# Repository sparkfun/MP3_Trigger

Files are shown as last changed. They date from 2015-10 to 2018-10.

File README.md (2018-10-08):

MP3 Trigger
============

MP3 Trigger (https://cdn.sparkfun.com/assets/parts/1/1/2/2/7/13720-01.jpg)

[*MP3 Trigger (WIG-13720)*](https://www.sparkfun.com/products/13720)

 The MP3 Trigger board is built to make it MP3 sound integration easier than ever. 
 The board has 18 external trigger pins that will directly trigger pre-selected MP3 tracks, and a full-duplex serial control port that provides full transport control, remote triggering for up to 256 tracks, and fast real-time volume control. 
 
Repository Contents
-------------------
* **/Hardware** - All Eagle design files (.brd, .sch)
* **/Production** - Production files

Documentation
--------------
* **[Hookup Guide](https://learn.sparkfun.com/tutorials/mp3-trigger-hookup-guide-v24)** - Basic hookup guide for the MP3 Trigger.
* **[SparkFun Fritzing repo](https://github.com/sparkfun/Fritzing_Parts)** - Fritzing diagrams for SparkFun products.
* **[SparkFun 3D Model repo](https://github.com/sparkfun/3D_Models)** - 3D models of SparkFun products. 
* **[SparkFun Graphical Datasheets](https://github.com/sparkfun/Graphical_Datasheets)** -Graphical Datasheets for various SparkFun products.

License Information
-------------------

This product is _**open source**_! 

Please review the LICENSE.md file for license information. 

If you have any questions or concerns on licensing, please contact techsupport@sparkfun.com.

Distributed as-is; no warranty is given.

- Your friends at SparkFun.

_**Note:** This product is a collaboration with Robertsonics. A portion of each sales goes back to them for product support and continued development._

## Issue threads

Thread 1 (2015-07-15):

v24 Proto Checklist Issues

ericorosel, 2015-07-15:
(1) Sheet 2 needs a frame

(2) 7 4-way jumpers in sheet 2

(3) Dashed lines in SCH are on "Symbols" instead of "Info"

(4) LM1117 had wrong prefix

(5) Board "Dimension" outline is 10mil instead of 8mil

(6) I updated my Eagle_rules repo and loaded it into the design, it seemed to fix the via sizing issue. I'm think the DRU in the project is just outdated

(7) When the vias changed it threw a Clearance error/issue

(8) Need measures in BRD

(9) 1.8V vreg needs silk for footprint

that's it!

JoelEB, 2015-07-29:
(1) Sheet 2 needs a frame - Fixed

(2) 7 4-way jumpers in sheet 2 - Fixed

(3) Dashed lines in SCH are on "Symbols" instead of "Info" - Fixed

(4) LM1117 had wrong prefix - Changed to U4

(5) Board "Dimension" outline is 10mil instead of 8mil - Fixed

(6) I updated my Eagle_rules repo and loaded it into the design, it seemed to fix the via sizing issue. I'm think the DRU in the project is just outdated

(7) When the vias changed it threw a Clearance error/issue - Non-issue

(8) Need measures in BRD - Added

(9) 1.8V vreg needs silk for footprint - Added and synced

Closed 2015-07-29.

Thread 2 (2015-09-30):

v24 Reds Checklist

ericorosel, 2015-09-30:
ISSUES:
(1) The TRIG17 and TRIG18 nets need flag labels

(2) DPDT and Nav switches both have "U" as the prefix, should be "S"

(3) This might be the same issue that I mentioned on the proto checklist, if so, please omit: There is a clearance issue thrown on one of the vias under the PSoC. I have my DRC clearances set to 6 mil min.

(4) Looks like NAV switch and barrel need tNames and tValues elements in the BRD

Concerns/comments:
(1) Might be worth noting AC and DC coupled on the jumper key on the back of the board

(2) There are a couple instances throughout the design of traces exiting pads at an angle. While I don't think any of the examples would cause functional issues with the design, I think they are worth fixing before we order REDs quantities. IMO

(3) According to the checklist, BLUE is the standard color we want to use for "STAT" LEDs. The stat LED in the design is green. I know there is a lot of documentation and support stuff on both Jamie's side and our's that reference the GREEN stat LED in the design. On that note, I think changing the LED to BLUE would be more trouble than it is worth. This is more of a CYA to show it was thought of.

(4) Looks like the design contains mostly 10 mil traces, but there are some 8 mil traces sprinkled around. I understand using smaller traces if a smaller pad necessitates it, but I can't see the reasoning for some of the 8 mil traces in the design. eg. See the "T" intersection on the "3.3V" trace near the R12 resistor. Again, I don't think function will be affected if the design stays as is, but I think it would make the design better to eliminate un-necessarily small trace widths. IMO

That's it.

JoelEB, 2015-10-01:
1) Fixed
2) Renamed
3) Fixed
4) Not sure what you mean. Is this the same issue we had that was just different on my computer vs yours?

1) Added
2)Tried to get as many as I could
3) I'm not changing the LED at this stage.
4) bumped up as many as I could to 10 mil

Closed 2015-10-01.

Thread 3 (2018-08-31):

Parallel play of multiple Files

Hernandiaz035, 2018-08-31:
I Would like to play a sound after every interrupt on a system, but I need that the playing of each instance of every sound continue until finish each file, Is it possible with this device or exists a firmware wich could afford this?

nseidle, 2018-09-05:
The MP3 trigger can only play one song at a time but the [Tsunami](https://www.sparkfun.com/products/13810) can play up to 32 mono tracks at the same time, starting and stopping independently.

Closed 2018-09-05.

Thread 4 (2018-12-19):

MP3 Trigger V2

HeadElf, 2018-12-19:
We have around 1000 units of the MP3 Trigger in our products however since last year we've noticed a repeated issue across a selected few units, so this is a request fro someone with a fair amount of knowledge regarding their functionality.  I've tried to succinctly get the points across below:

- There seems to be no pattern how the units fail but they hang with the green status light illuminated and are unresponsive to the manual stop start/track up/down switch.
- The only way to restart the MP3 players in this condition is to restart them with a power down.
- Once a unit fails it will fail on the same track at the same place each time. However if the SD card is analysed in any way the fault will disappear or move to another track.
- For some time we thought this problem could only be a attributable to faulty blocks on the SD cards, however when we use Partition Pro to analyse the cards, no problems are found.
- We have then removed the MicroSD card from one of these “faulty” products and transferred it to one of our new ones and the same problem occurs in the exact same place on the exact same track, yet this MicroSD card has performed perfectly for perhaps 12 weeks before the error occurred and the file when viewed on a PC has no discernible issues.
- Replacing the MicroSD card with a new, formatted card solves the problem as far as we can tell and reformatting the problem card means it is then reusable in another MP3 player, and the player as yet has not experienced another fault.

What we would like to know, is whether there is anything anyone is aware of that could cause this error perhaps in corrupting the cards or in the actual decoder chip etc.?  We recently noticed we had an MP3 track with a lot of MetaData on it at the start, which meant that the track began as normal, but it was about 1 minute before the audio kicked in – presumably because it had to parse the data before the audio stream began decoding.  Does MetaData affect the MP3 player? Perhaps it stumbles over a mis-read block of data or similar?

Any ideas on the matter will be greatly received.

lewispg228, 2018-12-19:
Hey @HeadElf , Sorry to hear you are having some trouble with the MP3 trigger. I'm not sure what is going on exactly, but I had some similar random issues on an [audio project of mine](https://www.sparkfun.com/news/2696) that involved using the [Tsunami WAV Trigger](https://www.sparkfun.com/products/13810), and it ended up being the file allocation size setting I had when I was formatting the uSD cards.

It turns out that when dealing with audio files, this is really important that they be at least 32 kilobytes. If it is set too small (my original mistake), then you will see some random failures. At least this was the case on the Tsunami board I was using, so I'm guessing that it could be a similar issue with the MP3 Trigger.

I will also reach out to the [primary engineer](https://robertsonics.com/about-2/) on this product, and see if we can come up with any other ideas worth trying.

For now, please check out this [troubleshooting tip](https://learn.sparkfun.com/tutorials/tsunami-hookup-guide#tsunami-demonstration) on the Tsunami WAV trigger hookup guide for help with the file allocation setting thing.

Hope this helps, and please let us know how it goes.

-Pete

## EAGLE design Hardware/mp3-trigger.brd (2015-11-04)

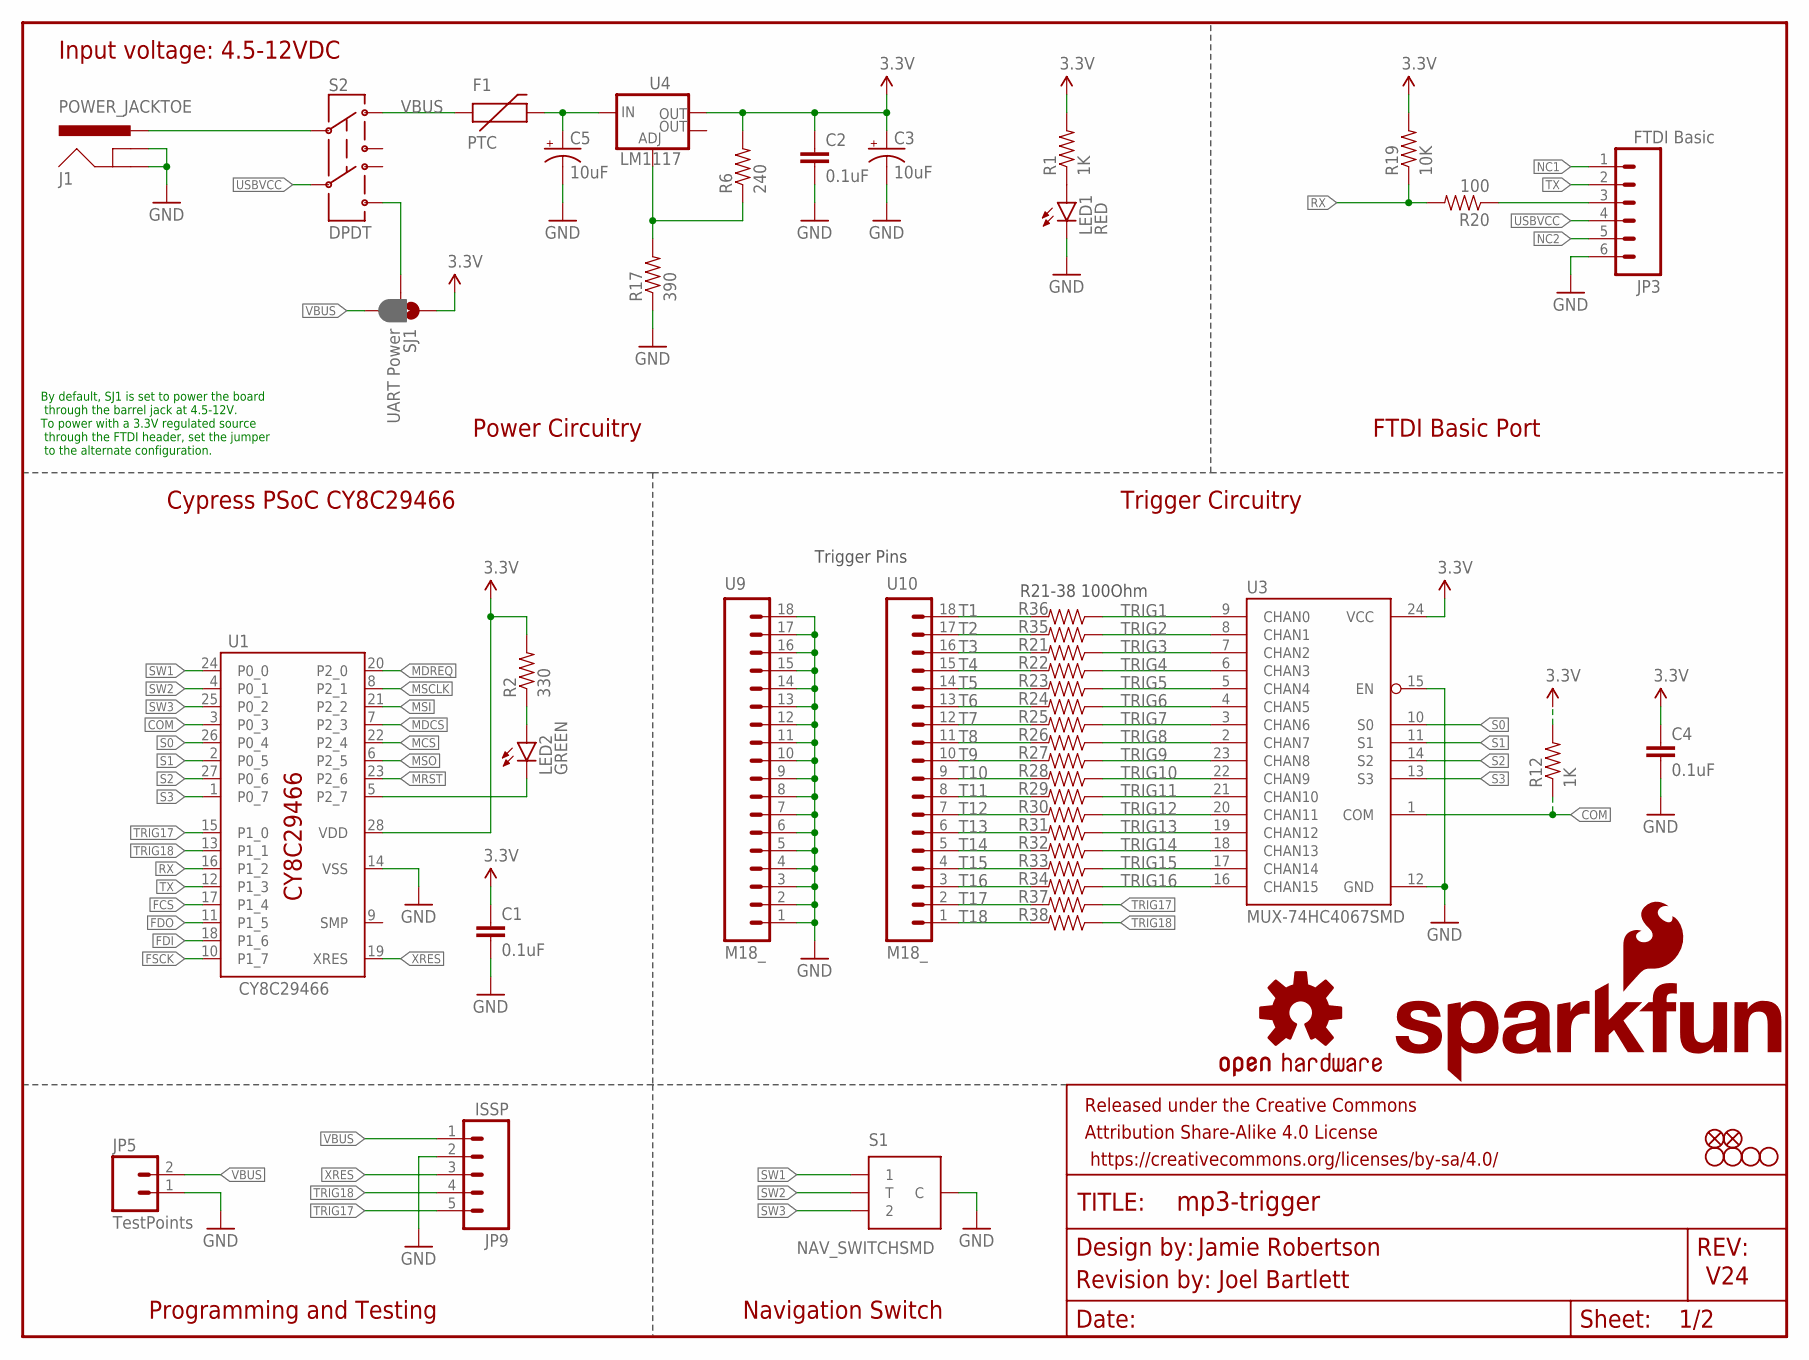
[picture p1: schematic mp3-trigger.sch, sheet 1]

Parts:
C1, C2, C4: 0.1uF; 0603-CAP
C3, C5: 10uF; EIA3216
F1: PTC; PTC-1206
FRAME3: FRAME-LETTER; CREATIVE_COMMONS
J1: POWER_JACKTOE; POWER_JACK_SMD_OVERPASTE_TOE
JP3: FTDI Basic; 1X06
JP5: TestPoints; 1X02
JP6, JP7: FIDUCIAL1X2; FIDUCIAL-1X2
JP9: ISSP; 1X05
LED1: RED; LED-1206
LED2: GREEN; LED-1206
LOGO3: OSHW-LOGOM; OSHW-LOGO-M
R1, R12: 1K; 0603-RES
R2: 330; 0603-RES
R6: 240; 0603-RES
R17: 390; 0603-RES
R19: 10K; 0603-RES
R20, R21, R22, R23, R24, R25, R26, R27, R28, R29, R30, R31, R32, R33, R34, R35, R36, R37, R38: 100; 0603-RES
S1: NAV_SWITCHSMD; NAV_SWITCH
S2: DPDT; AYZ0202
SJ1: UART Power; PAD-JUMPER-3-2OF3_NC_BY_PASTE_YES_SILK_FULL_BOX
U1: CY8C29466; SOIC-28
U3: MUX-74HC4067SMD; SSOP24
U4: LM1117; SOT223
U9, U10: M18_; 1X18
U$1: SFE_LOGO_NAME_FLAME.2_INCH; SFE_LOGO_NAME_FLAME_.2
U$12, U$13, U$14, U$15: STAND-OFF

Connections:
3.3V: C1.1, C2.1, C3.A (+), C4.1, R1.2, R2.2, R6.2, R12.2, R19.2, SJ1.1, U1.28 (VDD), U3.24 (VCC), U4.2 (OUT); also elsewhere on the board
COM: R12.1, U1.3 (P0_3), U3.1 (COM)
FCS: U1.17 (P1_4); also elsewhere on the board
FDI: U1.18 (P1_6); also elsewhere on the board
FDO: U1.11 (P1_5); also elsewhere on the board
FSCK: U1.10 (P1_7); also elsewhere on the board
GND: C1.2, C2.2, C3.C (-), C4.2, C5.C (-), J1.GND (GNDBREAK), J1.P$4 (GND), JP3.6, JP5.1, JP9.2, LED1.C, R17.1, S1.C, U1.14 (VSS), U3.12 (GND), U3.15 (EN), U9.1, U9.2, U9.3, U9.4, U9.5, U9.6, U9.7, U9.8, U9.9, U9.10, U9.11, U9.12, U9.13, U9.14, U9.15, U9.16, U9.17, U9.18; also elsewhere on the board
MCS: U1.22 (P2_4); also elsewhere on the board
MDCS: U1.7 (P2_3); also elsewhere on the board
MDREQ: U1.20 (P2_0); also elsewhere on the board
MRST: U1.23 (P2_6); also elsewhere on the board
MSCLK: U1.8 (P2_1); also elsewhere on the board
MSI: U1.21 (P2_2); also elsewhere on the board
MSO: U1.6 (P2_5); also elsewhere on the board
unnamed: R6.1, R17.2, U4.1 (ADJ)
unnamed: LED1.A, R1.1
unnamed: LED2.A, R2.1
unnamed: LED2.C, U1.5 (P2_7)
unnamed: J1.VIN0 (PWR), S2.2
unnamed: C5.A (+), F1.2, U4.3 (IN)
unnamed: S2.6, SJ1.2
NC1: JP3.1
NC2: JP3.5
RX: R19.1, R20.2, U1.16 (P1_2)
RX-I: JP3.3, R20.1
S0: U1.26 (P0_4), U3.10 (S0)
S1: U1.2 (P0_5), U3.11 (S1)
S2: U1.27 (P0_6), U3.14 (S2)
S3: U1.1 (P0_7), U3.13 (S3)
SW1: S1.1, U1.24 (P0_0)
SW2: S1.T, U1.4 (P0_1)
SW3: S1.2, U1.25 (P0_2)
T1: R36.2, U10.18
T2: R35.2, U10.17
T3: R21.2, U10.16
T4: R22.2, U10.15
T5: R23.2, U10.14
T6: R24.2, U10.13
T7: R25.2, U10.12
T8: R26.2, U10.11
T9: R27.2, U10.10
T10: R28.2, U10.9
T11: R29.2, U10.8
T12: R30.2, U10.7
T13: R31.2, U10.6
T14: R32.2, U10.5
T15: R33.2, U10.4
T16: R34.2, U10.3
T17: R37.2, U10.2
T18: R38.2, U10.1
TRIG1: R36.1, U3.9 (CHAN0)
TRIG2: R35.1, U3.8 (CHAN1)
TRIG3: R21.1, U3.7 (CHAN2)
TRIG4: R22.1, U3.6 (CHAN3)
TRIG5: R23.1, U3.5 (CHAN4)
TRIG6: R24.1, U3.4 (CHAN5)
TRIG7: R25.1, U3.3 (CHAN6)
TRIG8: R26.1, U3.2 (CHAN7)
TRIG9: R27.1, U3.23 (CHAN8)
TRIG10: R28.1, U3.22 (CHAN9)
TRIG11: R29.1, U3.21 (CHAN10)
TRIG12: R30.1, U3.20 (CHAN11)
TRIG13: R31.1, U3.19 (CHAN12)
TRIG14: R32.1, U3.18 (CHAN13)
TRIG15: R33.1, U3.17 (CHAN14)
TRIG16: R34.1, U3.16 (CHAN15)
TRIG17: JP9.5, R37.1, U1.15 (P1_0)
TRIG18: JP9.4, R38.1, U1.13 (P1_1)
TX: JP3.2, U1.12 (P1_3)
USBVCC: JP3.4, S2.5
VBUS: F1.1, JP5.2, JP9.1, S2.1, SJ1.3
XRES: JP9.3, U1.19 (XRES)

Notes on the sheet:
R21-38 100Ohm
Trigger Pins
Jamie Robertson
Revision by: Joel Bartlett
V24
FTDI Basic Port
Power Circuitry
Trigger Circuitry
Cypress PSoC CY8C29466
Navigation Switch
Programming and Testing
Input voltage: 4.5-12VDC
By default, SJ1 is set to power the board through the barrel jack at 4.5-12V. To power with a 3.3V regulated source through the FTDI header, set the jumper to the alternate configuration.

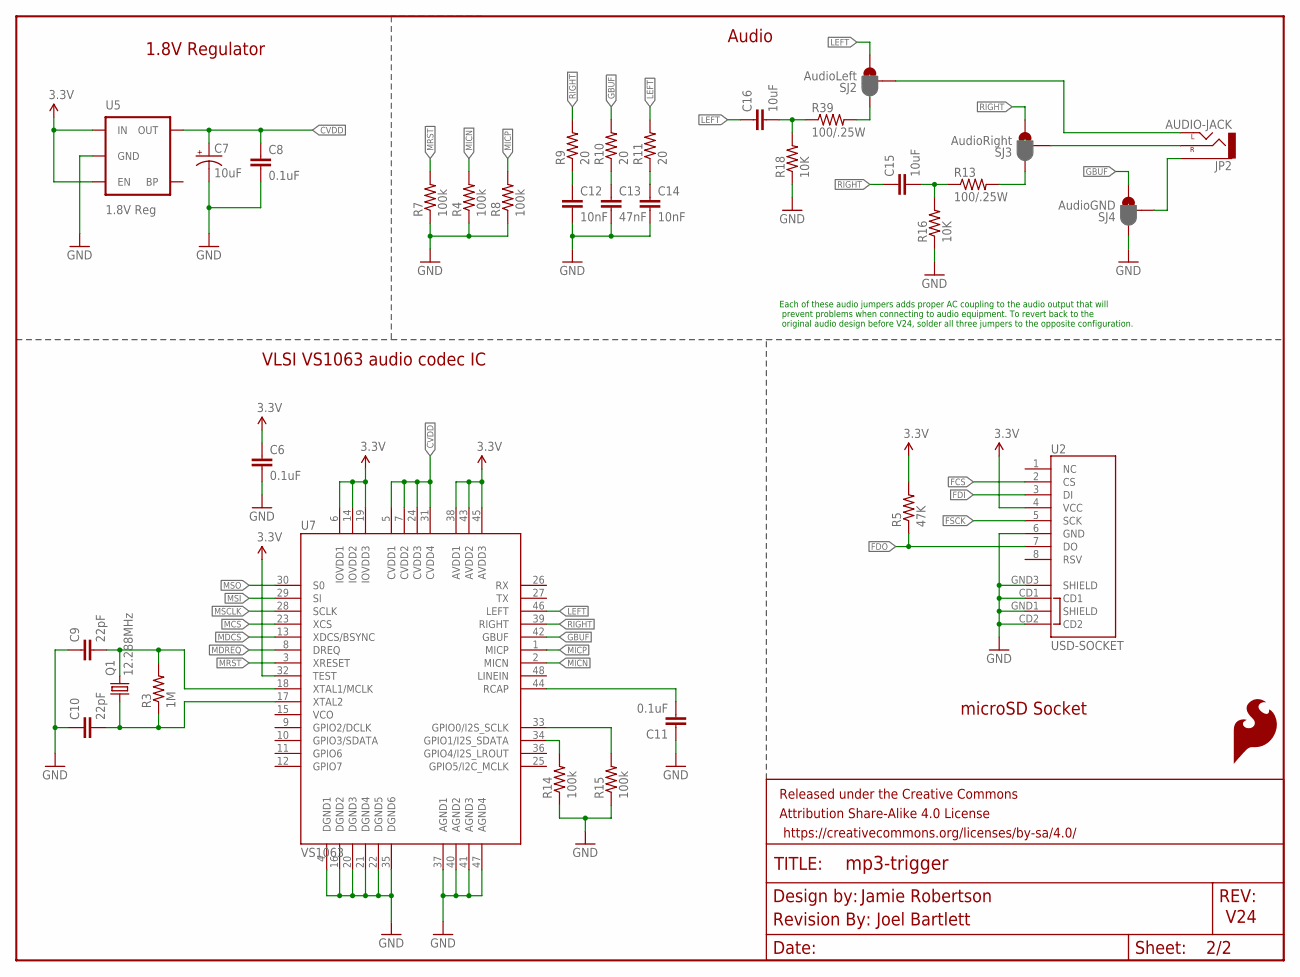
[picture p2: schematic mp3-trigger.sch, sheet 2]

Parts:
C6, C8, C11: 0.1uF; 0603-CAP
C7: 10uF; EIA3216
C9, C10: 22pF; 0603-CAP
C12, C14: 10nF; 0603-CAP
C13: 47nF; 0603-CAP
C15, C16: 10uF; 0603-CAP
FRAME1: FRAME-LETTERNO_PACKAGE; DUMMY
JP2: AUDIO-JACK; AUDIO-JACK-3.5MM-SMD
LOGO1: SFE_LOGO_FLAME.3_INCH; SFE_LOGO_FLAME_.3
Q1: 12.288MHz; CRYSTAL-SMD-5X3
R3: 1M; 0603-RES
R4, R7, R8, R14, R15: 100k; 0603-RES
R5: 47K; 0603-RES
R9, R10, R11: 20; 0603-RES
R13, R39: 100/.25W; 0603-RES
R16, R18: 10K; 0603-RES
SJ2: AudioLeft; PAD-HUMPER-3-1&2_NC_BY_PASTE_YES_SILK_FULL_BOX
SJ3: AudioRight; PAD-HUMPER-3-1&2_NC_BY_PASTE_YES_SILK_FULL_BOX
SJ4: AudioGND; PAD-HUMPER-3-1&2_NC_BY_PASTE_YES_SILK_FULL_BOX
U2: USD-SOCKET; MICROSD_1:1
U5: 1.8V Reg; SC70
U7: VS1063; LQFP-48
U$4: REVISION

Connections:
3.3V: C6.1, R5.2, U2.4 (VCC), U5.1 (IN), U5.3 (EN), U7.6 (IOVDD1), U7.14 (IOVDD2), U7.19 (IOVDD3), U7.32 (TEST), U7.38 (AVDD1), U7.43 (AVDD2), U7.45 (AVDD3); also elsewhere on the board
CVDD: C7.A (+), C8.1, U5.5 (OUT), U7.5 (CVDD1), U7.7 (CVDD2), U7.24 (CVDD3), U7.31 (CVDD4)
FCS: U2.2 (CS); also elsewhere on the board
FDI: U2.3 (DI); also elsewhere on the board
FDO: R5.1, U2.7 (DO); also elsewhere on the board
FSCK: U2.5 (SCK); also elsewhere on the board
GBUF: R10.2, SJ4.3, U7.42 (GBUF)
GND: C6.2, C7.C (-), C8.2, C9.1, C10.1, C11.1, C12.2, C13.2, C14.2, R4.1, R7.1, R8.1, R14.1, R15.1, R16.1, R18.1, SJ4.1, U2.6 (GND), U2.CD1, U2.CD2, U2.GND1 (SHIELD), U2.GND3 (SHIELD), U5.2 (GND), U7.4 (DGND1), U7.16 (DGND2), U7.20 (DGND3), U7.21 (DGND4), U7.22 (DGND5), U7.35 (DGND6), U7.37 (AGND1), U7.40 (AGND2), U7.41 (AGND3), U7.47 (AGND4); also elsewhere on the board
LEFT: C16.1, R11.2, SJ2.3, U7.46 (LEFT)
MCS: U7.23 (XCS); also elsewhere on the board
MDCS: U7.13 (XDCS/BSYNC); also elsewhere on the board
MDREQ: U7.8 (DREQ); also elsewhere on the board
MICN: R4.2, U7.2 (MICN)
MICP: R8.2, U7.1 (MICP)
MRST: R7.2, U7.3 (XRESET); also elsewhere on the board
MSCLK: U7.28 (SCLK); also elsewhere on the board
MSI: U7.29 (SI); also elsewhere on the board
MSO: U7.30 (S0); also elsewhere on the board
unnamed: JP2.SLEEVE, SJ4.2
unnamed: C9.2, Q1.3 (2), R3.2, U7.18 (XTAL1/MCLK)
unnamed: C10.2, Q1.1, R3.1, U7.17 (XTAL2)
unnamed: JP2.RING (RIGHT), SJ3.2
unnamed: R13.2, SJ3.1
unnamed: C15.2, R13.1, R16.2
unnamed: R14.2, U7.34 (GPIO1/I2S_SDATA)
unnamed: C11.2, U7.44 (RCAP)
unnamed: C14.1, R11.1
unnamed: C13.1, R10.1
unnamed: C12.1, R9.1
unnamed: R15.2, U7.33 (GPIO0/I2S_SCLK)
unnamed: JP2.TIP (LEFT), SJ2.2
unnamed: R39.2, SJ2.1
unnamed: C16.2, R18.2, R39.1
RIGHT: C15.1, R9.2, SJ3.3, U7.39 (RIGHT)

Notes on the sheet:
Jamie Robertson
Joel Bartlett
V24
VLSI VS1063 audio codec IC
microSD Socket
Audio
1.8V Regulator
Each of these audio jumpers adds proper AC coupling to the audio output that will prevent problems when connecting to audio equipment. To revert back to the original audio design before V24, solder all three jumpers to the opposite configuration.

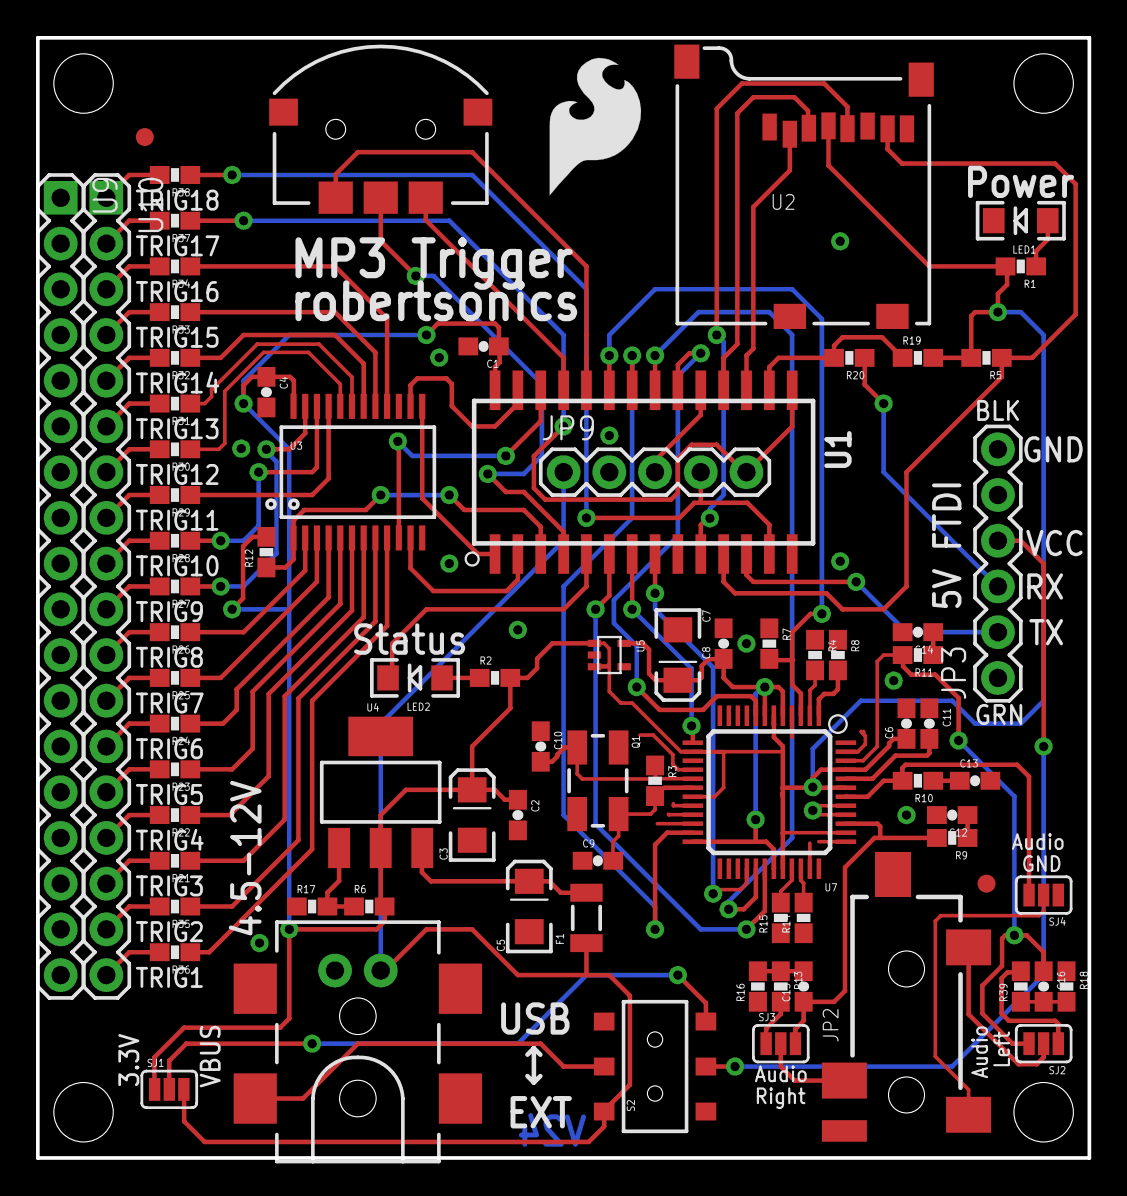
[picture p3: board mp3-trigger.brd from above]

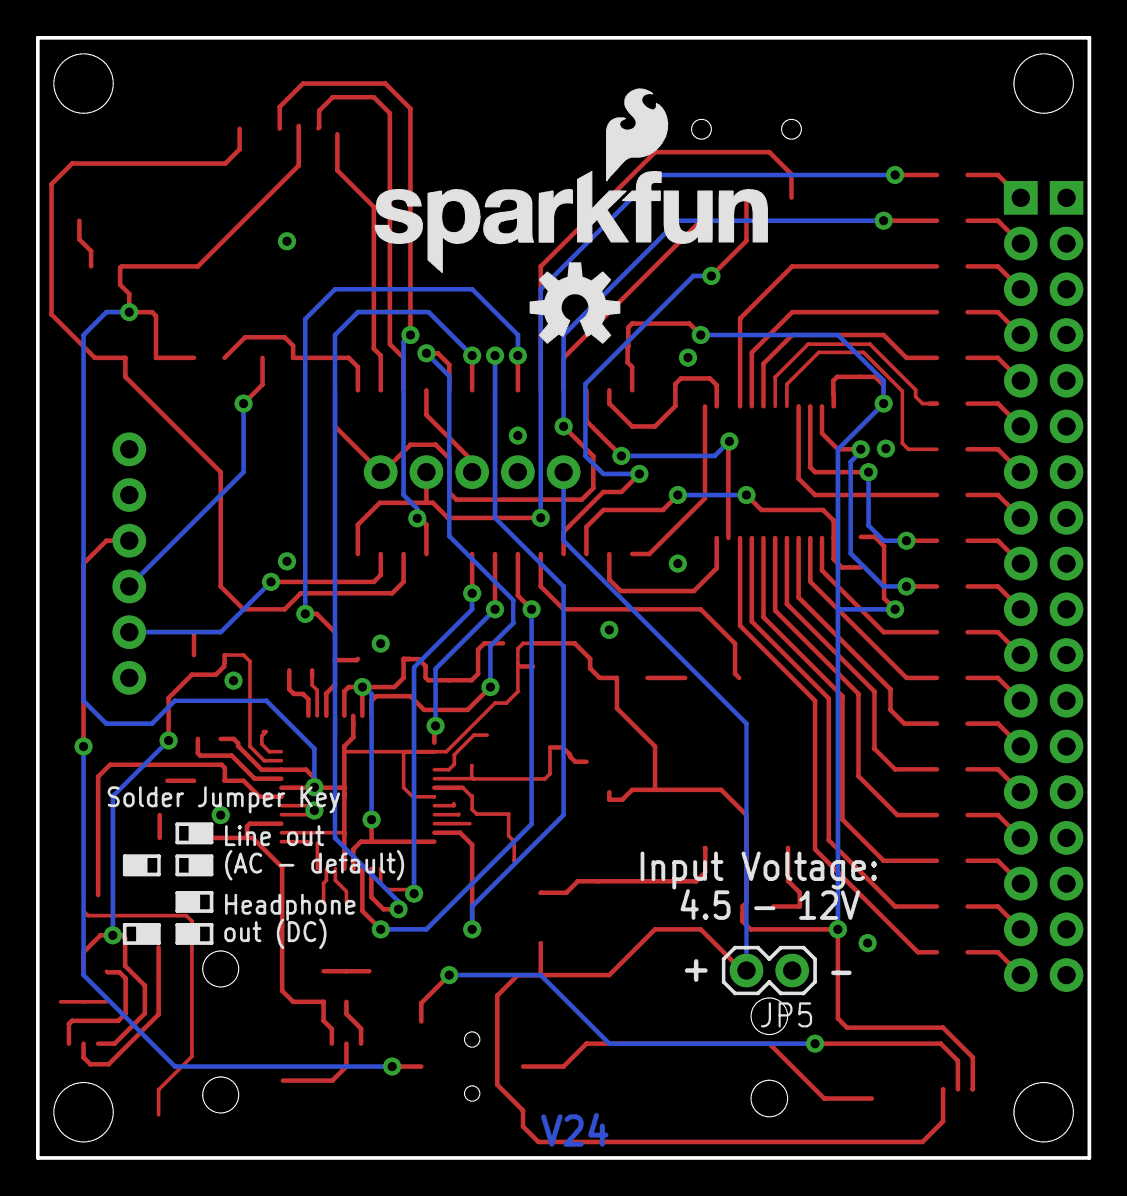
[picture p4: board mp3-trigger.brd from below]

Board: 2 copper layers, 58.4 x 62.2 mm, 90 parts (3 on the bottom side), 91 nets.

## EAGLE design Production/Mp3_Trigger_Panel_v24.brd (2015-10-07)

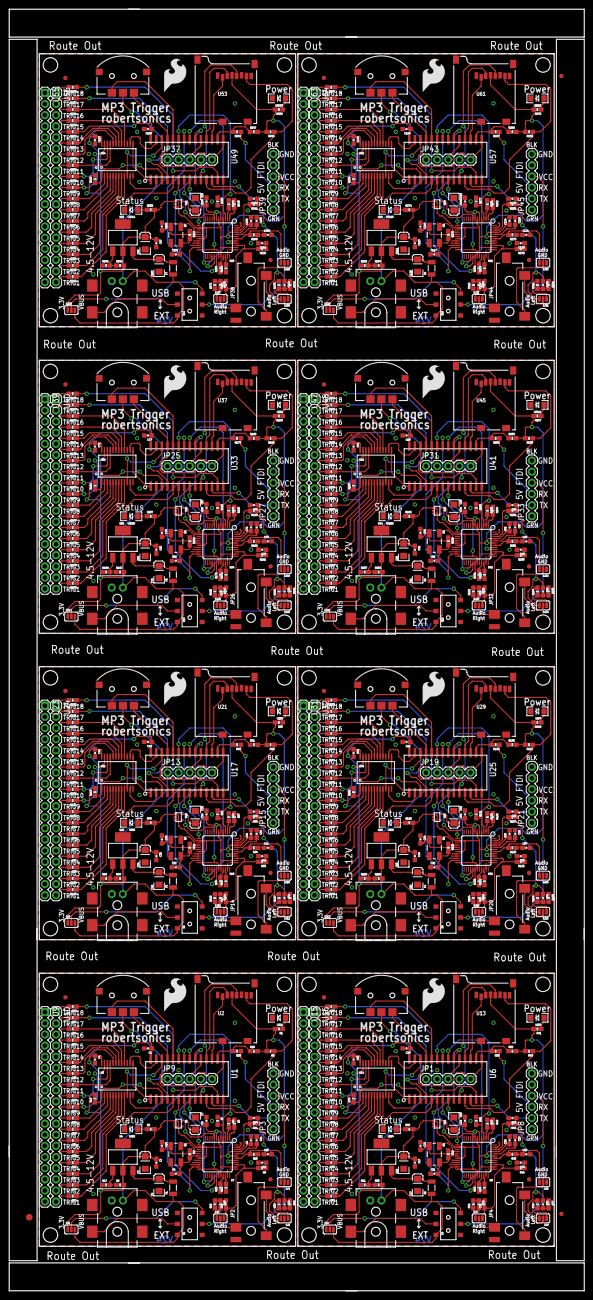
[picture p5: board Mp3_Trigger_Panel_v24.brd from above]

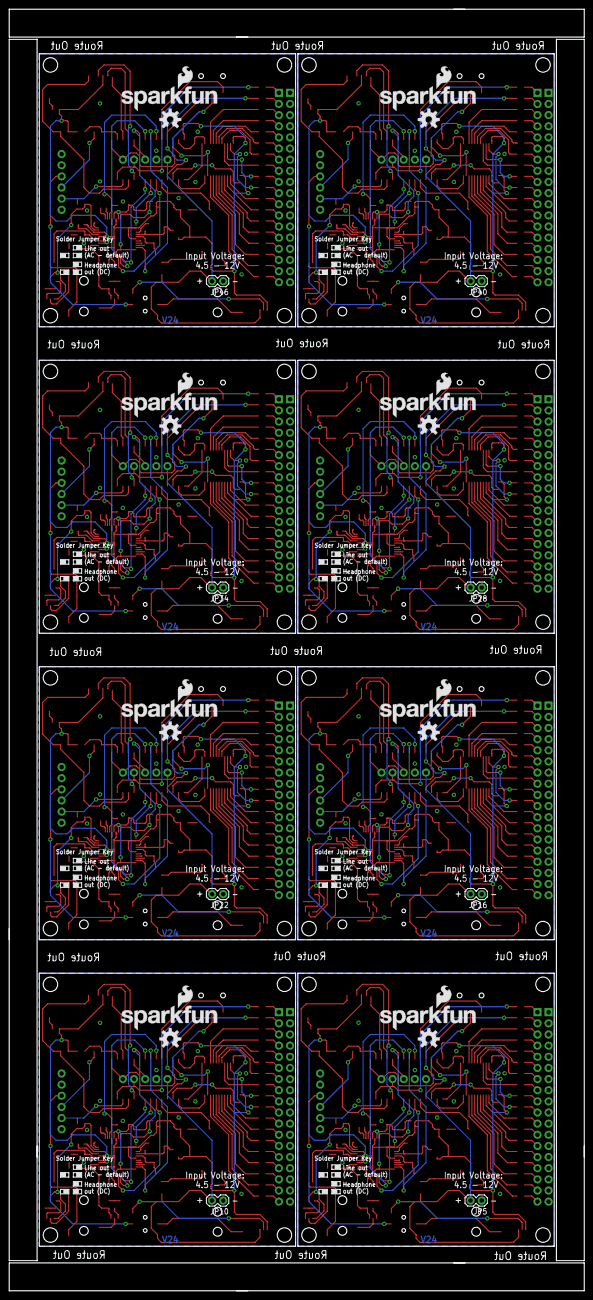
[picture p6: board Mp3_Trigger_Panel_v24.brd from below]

Board: 2 copper layers, 131.1 x 292.1 mm, 699 parts (24 on the bottom side), 728 nets.

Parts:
C1, C2, C4, C6, C8, C11, C17, C20, C23, C28, C29, C30, C33, C36, C39, C44, C45, C46, C49, C52, C55, C60, C61, C62, C65, C68, C71, C76, C77, C78, C81, C84, C87, C92, C93, C94, C97, C100, C103, C108, C109, C110, C113, C116, C119, C124, C125, C126: 0.1uF; 0603-CAP
C3, C5, C7, C18, C19, C27, C34, C35, C43, C50, C51, C59, C66, C67, C75, C82, C83, C91, C98, C99, C107, C114, C115, C123: 10uF; EIA3216
C9, C10, C21, C22, C37, C38, C53, C54, C69, C70, C85, C86, C101, C102, C117, C118: 22pF; 0603-CAP
C12, C14, C24, C26, C40, C42, C56, C58, C72, C74, C88, C90, C104, C106, C120, C122: 10nF; 0603-CAP
C13, C25, C41, C57, C73, C89, C105, C121: 47nF; 0603-CAP
C15, C16, C31, C32, C47, C48, C63, C64, C79, C80, C95, C96, C111, C112, C127, C128: 10uF; 0603-CAP
E$1: FIDUCIAL-1.5X3
E$5, E$6: FIDUCIAL-1X2
F1, F2, F3, F4, F5, F6, F7, F8: PTC; PTC-1206
J1, J2, J3, J4, J5, J6, J7, J8: POWER_JACKTOE; POWER_JACK_SMD_OVERPASTE_TOE
JP1, JP9, JP13, JP19, JP25, JP31, JP37, JP43: ISSP; 1X05
JP2, JP4, JP14, JP20, JP26, JP32, JP38, JP44: AUDIO-JACK; AUDIO-JACK-3.5MM-SMD
JP3, JP8, JP15, JP21, JP27, JP33, JP39, JP45: FTDI Basic; 1X06
JP5, JP10, JP16, JP22, JP28, JP34, JP40, JP46: TestPoints; 1X02
JP6, JP7, JP11, JP12, JP17, JP18, JP23, JP24, JP29, JP30, JP35, JP36, JP41, JP42, JP47, JP48: FIDUCIAL1X2; FIDUCIAL-1X2
LED1, LED3, LED5, LED7, LED9, LED11, LED13, LED15: RED; LED-1206
LED2, LED4, LED6, LED8, LED10, LED12, LED14, LED16: GREEN; LED-1206
LOGO1, LOGO2, LOGO5, LOGO7, LOGO9, LOGO11, LOGO13, LOGO15: SFE_LOGO_FLAME.3_INCH; SFE_LOGO_FLAME_.3
LOGO3, LOGO4, LOGO6, LOGO8, LOGO10, LOGO12, LOGO14, LOGO16: OSHW-LOGOM; OSHW-LOGO-M
Q1, Q2, Q3, Q4, Q5, Q6, Q7, Q8: 12.288MHz; CRYSTAL-SMD-5X3
R1, R12, R41, R74, R80, R113, R119, R152, R158, R191, R197, R230, R236, R269, R275, R308: 1K; 0603-RES
R2, R40, R79, R118, R157, R196, R235, R274: 330; 0603-RES
R3, R42, R81, R120, R159, R198, R237, R276: 1M; 0603-RES
R4, R7, R8, R14, R15, R43, R47, R48, R54, R55, R82, R86, R87, R93, R94, R121, R125, R126, R132, R133, R160, R164, R165, R171, R172, R199, R203, R204, R210, R211, R238, R242, R243, R249, R250, R277, R281, R282, R288, R289: 100k; 0603-RES
R5, R49, R88, R127, R166, R205, R244, R283: 47K; 0603-RES
R6, R50, R89, R128, R167, R206, R245, R284: 240; 0603-RES
R9, R10, R11, R44, R45, R46, R83, R84, R85, R122, R123, R124, R161, R162, R163, R200, R201, R202, R239, R240, R241, R278, R279, R280: 20; 0603-RES
R13, R39, R75, R78, R114, R117, R153, R156, R192, R195, R231, R234, R270, R273, R309, R312: 100/.25W; 0603-RES
R16, R18, R19, R52, R76, R77, R91, R115, R116, R130, R154, R155, R169, R193, R194, R208, R232, R233, R247, R271, R272, R286, R310, R311: 10K; 0603-RES
R17, R51, R90, R129, R168, R207, R246, R285: 390; 0603-RES
R20, R21, R22, R23, R24, R25, R26, R27, R28, R29, R30, R31, R32, R33, R34, R35, R36, R37, R38, R53, R56, R57, R58, R59, R60, R61, R62, R63, R64, R65, R66, R67, R68, R69, R70, R71, R72, R73, R92, R95, R96, R97, R98, R99, R100, R101, R102, R103, R104, R105, R106, R107, R108, R109, R110, R111, R112, R131, R134, R135, R136, R137, R138, R139, R140, R141, R142, R143, R144, R145, R146, R147, R148, R149, R150, R151, R170, R173, R174, R175, R176, R177, R178, R179, R180, R181, R182, R183, R184, R185, R186, R187, R188, R189, R190, R209, R212, R213, R214, R215, R216, R217, R218, R219, R220, R221, R222, R223, R224, R225, R226, R227, R228, R229, R248, R251, R252, R253, R254, R255, R256, R257, R258, R259, R260, R261, R262, R263, R264, R265, R266, R267, R268, R287, R290, R291, R292, R293, R294, R295, R296, R297, R298, R299, R300, R301, R302, R303, R304, R305, R306, R307: 100; 0603-RES
S1, S3, S5, S7, S9, S11, S13, S15: NAV_SWITCHSMD; NAV_SWITCH
S2, S4, S6, S8, S10, S12, S14, S16: DPDT; AYZ0202
SJ1, SJ5, SJ9, SJ13, SJ17, SJ21, SJ25, SJ29: UART Power; PAD-JUMPER-3-2OF3_NC_BY_PASTE_YES_SILK_FULL_BOX
SJ2, SJ8, SJ12, SJ16, SJ20, SJ24, SJ28, SJ32: AudioLeft; PAD-HUMPER-3-1&2_NC_BY_PASTE_YES_SILK_FULL_BOX
SJ3, SJ7, SJ11, SJ15, SJ19, SJ23, SJ27, SJ31: AudioRight; PAD-HUMPER-3-1&2_NC_BY_PASTE_YES_SILK_FULL_BOX
SJ4, SJ6, SJ10, SJ14, SJ18, SJ22, SJ26, SJ30: AudioGND; PAD-HUMPER-3-1&2_NC_BY_PASTE_YES_SILK_FULL_BOX
U1, U6, U17, U25, U33, U41, U49, U57: CY8C29466; SOIC-28
U2, U13, U21, U29, U37, U45, U53, U61: USD-SOCKET; MICROSD_1:1
U3, U14, U22, U30, U38, U46, U54, U62: MUX-74HC4067SMD; SSOP24
U4, U12, U20, U28, U36, U44, U52, U60: LM1117; SOT223
U5, U11, U19, U27, U35, U43, U51, U59: 1.8V Reg; SC70
U7, U8, U18, U26, U34, U42, U50, U58: VS1063; LQFP-48
U9, U10, U15, U16, U23, U24, U31, U32, U39, U40, U47, U48, U55, U56, U63, U64: M18_; 1X18
U$1, U$2, U$7, U$16, U$21, U$26, U$31, U$36: SFE_LOGO_NAME_FLAME.2_INCH; SFE_LOGO_NAME_FLAME_.2
U$3, U$4, U$5, U$6, U$8, U$9, U$10, U$11, U$12, U$13, U$14, U$15, U$17, U$18, U$19, U$20, U$22, U$23, U$24, U$25, U$27, U$28, U$29, U$30, U$32, U$33, U$34, U$35, U$37, U$38, U$39, U$40: STAND-OFF

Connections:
3.3V: C1.1, C2.1, C3.A, C4.1, C6.1, R1.2, R2.2, R5.2, R6.2, R12.2, R19.2, SJ1.1, U1.28, U2.4, U3.24, U4.2, U5.1, U5.3, U7.6, U7.14, U7.19, U7.32, U7.38, U7.43, U7.45
3.3V1: C17.1, C18.A, C28.1, C29.1, C30.1, R40.2, R41.2, R49.2, R50.2, R52.2, R74.2, SJ5.1, U6.28, U8.6, U8.14, U8.19, U8.32, U8.38, U8.43, U8.45, U11.1, U11.3, U12.2, U13.4, U14.24
3.3V2: C33.1, C34.A, C44.1, C45.1, C46.1, R79.2, R80.2, R88.2, R89.2, R91.2, R113.2, SJ9.1, U17.28, U18.6, U18.14, U18.19, U18.32, U18.38, U18.43, U18.45, U19.1, U19.3, U20.2, U21.4, U22.24
3.3V3: C49.1, C50.A, C60.1, C61.1, C62.1, R118.2, R119.2, R127.2, R128.2, R130.2, R152.2, SJ13.1, U25.28, U26.6, U26.14, U26.19, U26.32, U26.38, U26.43, U26.45, U27.1, U27.3, U28.2, U29.4, U30.24
3.3V4: C65.1, C66.A, C76.1, C77.1, C78.1, R157.2, R158.2, R166.2, R167.2, R169.2, R191.2, SJ17.1, U33.28, U34.6, U34.14, U34.19, U34.32, U34.38, U34.43, U34.45, U35.1, U35.3, U36.2, U37.4, U38.24
3.3V5: C81.1, C82.A, C92.1, C93.1, C94.1, R196.2, R197.2, R205.2, R206.2, R208.2, R230.2, SJ21.1, U41.28, U42.6, U42.14, U42.19, U42.32, U42.38, U42.43, U42.45, U43.1, U43.3, U44.2, U45.4, U46.24
3.3V6: C97.1, C98.A, C108.1, C109.1, C110.1, R235.2, R236.2, R244.2, R245.2, R247.2, R269.2, SJ25.1, U49.28, U50.6, U50.14, U50.19, U50.32, U50.38, U50.43, U50.45, U51.1, U51.3, U52.2, U53.4, U54.24
3.3V7: C113.1, C114.A, C124.1, C125.1, C126.1, R274.2, R275.2, R283.2, R284.2, R286.2, R308.2, SJ29.1, U57.28, U58.6, U58.14, U58.19, U58.32, U58.38, U58.43, U58.45, U59.1, U59.3, U60.2, U61.4, U62.24
COM: R12.1, U1.3, U3.1
COM1: R74.1, U6.3, U14.1
COM2: R113.1, U17.3, U22.1
COM3: R152.1, U25.3, U30.1
COM4: R191.1, U33.3, U38.1
COM5: R230.1, U41.3, U46.1
COM6: R269.1, U49.3, U54.1
COM7: R308.1, U57.3, U62.1
CVDD: C7.A, C8.1, U5.5, U7.5, U7.7, U7.24, U7.31
CVDD1: C19.A, C20.1, U8.5, U8.7, U8.24, U8.31, U11.5
CVDD2: C35.A, C36.1, U18.5, U18.7, U18.24, U18.31, U19.5
CVDD3: C51.A, C52.1, U26.5, U26.7, U26.24, U26.31, U27.5
CVDD4: C67.A, C68.1, U34.5, U34.7, U34.24, U34.31, U35.5
CVDD5: C83.A, C84.1, U42.5, U42.7, U42.24, U42.31, U43.5
CVDD6: C99.A, C100.1, U50.5, U50.7, U50.24, U50.31, U51.5
CVDD7: C115.A, C116.1, U58.5, U58.7, U58.24, U58.31, U59.5
FCS: U1.17, U2.2
FCS1: U6.17, U13.2
FCS2: U17.17, U21.2
FCS3: U25.17, U29.2
FCS4: U33.17, U37.2
FCS5: U41.17, U45.2
FCS6: U49.17, U53.2
FCS7: U57.17, U61.2
FDI: U1.18, U2.3
FDI1: U6.18, U13.3
FDI2: U17.18, U21.3
FDI3: U25.18, U29.3
FDI4: U33.18, U37.3
FDI5: U41.18, U45.3
FDI6: U49.18, U53.3
FDI7: U57.18, U61.3
FDO: R5.1, U1.11, U2.7
FDO1: R49.1, U6.11, U13.7
FDO2: R88.1, U17.11, U21.7
FDO3: R127.1, U25.11, U29.7
FDO4: R166.1, U33.11, U37.7
FDO5: R205.1, U41.11, U45.7
FDO6: R244.1, U49.11, U53.7
FDO7: R283.1, U57.11, U61.7
FSCK: U1.10, U2.5
FSCK1: U6.10, U13.5
FSCK2: U17.10, U21.5
FSCK3: U25.10, U29.5
FSCK4: U33.10, U37.5
FSCK5: U41.10, U45.5
FSCK6: U49.10, U53.5
FSCK7: U57.10, U61.5
GBUF: R10.2, SJ4.3, U7.42
GBUF1: R45.2, SJ6.3, U8.42
GBUF2: R84.2, SJ10.3, U18.42
GBUF3: R123.2, SJ14.3, U26.42
GBUF4: R162.2, SJ18.3, U34.42
GBUF5: R201.2, SJ22.3, U42.42
GBUF6: R240.2, SJ26.3, U50.42
GBUF7: R279.2, SJ30.3, U58.42
GND: C1.2, C2.2, C3.C, C4.2, C5.C, C6.2, C7.C, C8.2, C9.1, C10.1, C11.1, C12.2, C13.2, C14.2, J1.GND, J1.P$4, JP3.6, JP5.1, JP9.2, LED1.C, R4.1, R7.1, R8.1, R14.1, R15.1, R16.1, R17.1, R18.1, S1.C, SJ4.1, U1.14, U2.6, U2.CD1, U2.CD2, U2.GND1, U2.GND3, U3.12, U3.15, U5.2, U7.4, U7.16, U7.20, U7.21, U7.22, U7.35, U7.37, U7.40, U7.41, U7.47, U9.1, U9.2, U9.3, U9.4, U9.5, U9.6, U9.7, U9.8, U9.9, U9.10, U9.11, U9.12, U9.13, U9.14, U9.15, U9.16, U9.17, U9.18
GND1: C17.2, C18.C, C19.C, C20.2, C21.1, C22.1, C23.1, C24.2, C25.2, C26.2, C27.C, C28.2, C29.2, C30.2, J2.GND, J2.P$4, JP1.2, JP8.6, JP10.1, LED3.C, R43.1, R47.1, R48.1, R51.1, R54.1, R55.1, R76.1, R77.1, S3.C, SJ6.1, U6.14, U8.4, U8.16, U8.20, U8.21, U8.22, U8.35, U8.37, U8.40, U8.41, U8.47, U11.2, U13.6, U13.CD1, U13.CD2, U13.GND1, U13.GND3, U14.12, U14.15, U15.1, U15.2, U15.3, U15.4, U15.5, U15.6, U15.7, U15.8, U15.9, U15.10, U15.11, U15.12, U15.13, U15.14, U15.15, U15.16, U15.17, U15.18
GND2: C33.2, C34.C, C35.C, C36.2, C37.1, C38.1, C39.1, C40.2, C41.2, C42.2, C43.C, C44.2, C45.2, C46.2, J3.GND, J3.P$4, JP13.2, JP15.6, JP16.1, LED5.C, R82.1, R86.1, R87.1, R90.1, R93.1, R94.1, R115.1, R116.1, S5.C, SJ10.1, U17.14, U18.4, U18.16, U18.20, U18.21, U18.22, U18.35, U18.37, U18.40, U18.41, U18.47, U19.2, U21.6, U21.CD1, U21.CD2, U21.GND1, U21.GND3, U22.12, U22.15, U23.1, U23.2, U23.3, U23.4, U23.5, U23.6, U23.7, U23.8, U23.9, U23.10, U23.11, U23.12, U23.13, U23.14, U23.15, U23.16, U23.17, U23.18
GND3: C49.2, C50.C, C51.C, C52.2, C53.1, C54.1, C55.1, C56.2, C57.2, C58.2, C59.C, C60.2, C61.2, C62.2, J4.GND, J4.P$4, JP19.2, JP21.6, JP22.1, LED7.C, R121.1, R125.1, R126.1, R129.1, R132.1, R133.1, R154.1, R155.1, S7.C, SJ14.1, U25.14, U26.4, U26.16, U26.20, U26.21, U26.22, U26.35, U26.37, U26.40, U26.41, U26.47, U27.2, U29.6, U29.CD1, U29.CD2, U29.GND1, U29.GND3, U30.12, U30.15, U31.1, U31.2, U31.3, U31.4, U31.5, U31.6, U31.7, U31.8, U31.9, U31.10, U31.11, U31.12, U31.13, U31.14, U31.15, U31.16, U31.17, U31.18
GND4: C65.2, C66.C, C67.C, C68.2, C69.1, C70.1, C71.1, C72.2, C73.2, C74.2, C75.C, C76.2, C77.2, C78.2, J5.GND, J5.P$4, JP25.2, JP27.6, JP28.1, LED9.C, R160.1, R164.1, R165.1, R168.1, R171.1, R172.1, R193.1, R194.1, S9.C, SJ18.1, U33.14, U34.4, U34.16, U34.20, U34.21, U34.22, U34.35, U34.37, U34.40, U34.41, U34.47, U35.2, U37.6, U37.CD1, U37.CD2, U37.GND1, U37.GND3, U38.12, U38.15, U39.1, U39.2, U39.3, U39.4, U39.5, U39.6, U39.7, U39.8, U39.9, U39.10, U39.11, U39.12, U39.13, U39.14, U39.15, U39.16, U39.17, U39.18
GND5: C81.2, C82.C, C83.C, C84.2, C85.1, C86.1, C87.1, C88.2, C89.2, C90.2, C91.C, C92.2, C93.2, C94.2, J6.GND, J6.P$4, JP31.2, JP33.6, JP34.1, LED11.C, R199.1, R203.1, R204.1, R207.1, R210.1, R211.1, R232.1, R233.1, S11.C, SJ22.1, U41.14, U42.4, U42.16, U42.20, U42.21, U42.22, U42.35, U42.37, U42.40, U42.41, U42.47, U43.2, U45.6, U45.CD1, U45.CD2, U45.GND1, U45.GND3, U46.12, U46.15, U47.1, U47.2, U47.3, U47.4, U47.5, U47.6, U47.7, U47.8, U47.9, U47.10, U47.11, U47.12, U47.13, U47.14, U47.15, U47.16, U47.17, U47.18
GND6: C97.2, C98.C, C99.C, C100.2, C101.1, C102.1, C103.1, C104.2, C105.2, C106.2, C107.C, C108.2, C109.2, C110.2, J7.GND, J7.P$4, JP37.2, JP39.6, JP40.1, LED13.C, R238.1, R242.1, R243.1, R246.1, R249.1, R250.1, R271.1, R272.1, S13.C, SJ26.1, U49.14, U50.4, U50.16, U50.20, U50.21, U50.22, U50.35, U50.37, U50.40, U50.41, U50.47, U51.2, U53.6, U53.CD1, U53.CD2, U53.GND1, U53.GND3, U54.12, U54.15, U55.1, U55.2, U55.3, U55.4, U55.5, U55.6, U55.7, U55.8, U55.9, U55.10, U55.11, U55.12, U55.13, U55.14, U55.15, U55.16, U55.17, U55.18
GND7: C113.2, C114.C, C115.C, C116.2, C117.1, C118.1, C119.1, C120.2, C121.2, C122.2, C123.C, C124.2, C125.2, C126.2, J8.GND, J8.P$4, JP43.2, JP45.6, JP46.1, LED15.C, R277.1, R281.1, R282.1, R285.1, R288.1, R289.1, R310.1, R311.1, S15.C, SJ30.1, U57.14, U58.4, U58.16, U58.20, U58.21, U58.22, U58.35, U58.37, U58.40, U58.41, U58.47, U59.2, U61.6, U61.CD1, U61.CD2, U61.GND1, U61.GND3, U62.12, U62.15, U63.1, U63.2, U63.3, U63.4, U63.5, U63.6, U63.7, U63.8, U63.9, U63.10, U63.11, U63.12, U63.13, U63.14, U63.15, U63.16, U63.17, U63.18
LEFT: C16.1, R11.2, SJ2.3, U7.46
LEFT1: C32.1, R46.2, SJ8.3, U8.46
LEFT2: C48.1, R85.2, SJ12.3, U18.46
LEFT3: C64.1, R124.2, SJ16.3, U26.46
LEFT4: C80.1, R163.2, SJ20.3, U34.46
LEFT5: C96.1, R202.2, SJ24.3, U42.46
LEFT6: C112.1, R241.2, SJ28.3, U50.46
LEFT7: C128.1, R280.2, SJ32.3, U58.46
MCS: U1.22, U7.23
MCS1: U6.22, U8.23
MCS2: U17.22, U18.23
MCS3: U25.22, U26.23
MCS4: U33.22, U34.23
MCS5: U41.22, U42.23
MCS6: U49.22, U50.23
MCS7: U57.22, U58.23
MDCS: U1.7, U7.13
MDCS1: U6.7, U8.13
MDCS2: U17.7, U18.13
MDCS3: U25.7, U26.13
MDCS4: U33.7, U34.13
MDCS5: U41.7, U42.13
MDCS6: U49.7, U50.13
MDCS7: U57.7, U58.13
MDREQ: U1.20, U7.8
MDREQ1: U6.20, U8.8
MDREQ2: U17.20, U18.8
MDREQ3: U25.20, U26.8
MDREQ4: U33.20, U34.8
MDREQ5: U41.20, U42.8
MDREQ6: U49.20, U50.8
MDREQ7: U57.20, U58.8
MICN: R4.2, U7.2
MICN1: R47.2, U8.2
MICN2: R86.2, U18.2
MICN3: R125.2, U26.2
MICN4: R164.2, U34.2
MICN5: R203.2, U42.2
MICN6: R242.2, U50.2
MICN7: R281.2, U58.2
MICP: R8.2, U7.1
MICP1: R48.2, U8.1
MICP2: R87.2, U18.1
MICP3: R126.2, U26.1
MICP4: R165.2, U34.1
MICP5: R204.2, U42.1
MICP6: R243.2, U50.1
MICP7: R282.2, U58.1
MRST: R7.2, U1.23, U7.3
MRST1: R43.2, U6.23, U8.3
MRST2: R82.2, U17.23, U18.3
MRST3: R121.2, U25.23, U26.3
MRST4: R160.2, U33.23, U34.3
MRST5: R199.2, U41.23, U42.3
MRST6: R238.2, U49.23, U50.3
MRST7: R277.2, U57.23, U58.3
MSCLK: U1.8, U7.28
MSCLK1: U6.8, U8.28
MSCLK2: U17.8, U18.28
MSCLK3: U25.8, U26.28
MSCLK4: U33.8, U34.28
MSCLK5: U41.8, U42.28
MSCLK6: U49.8, U50.28
MSCLK7: U57.8, U58.28
MSI: U1.21, U7.29
MSI1: U6.21, U8.29
MSI2: U17.21, U18.29
MSI3: U25.21, U26.29
MSI4: U33.21, U34.29
MSI5: U41.21, U42.29
MSI6: U49.21, U50.29
MSI7: U57.21, U58.29
MSO: U1.6, U7.30
MSO1: U6.6, U8.30
MSO2: U17.6, U18.30
MSO3: U25.6, U26.30
MSO4: U33.6, U34.30
MSO5: U41.6, U42.30
MSO6: U49.6, U50.30
MSO7: U57.6, U58.30
unnamed: JP2.SLEEVE, SJ4.2
unnamed: R6.1, R17.2, U4.1
unnamed: C9.2, Q1.3, R3.2, U7.18
unnamed: LED1.A, R1.1
unnamed: C10.2, Q1.1, R3.1, U7.17
unnamed: JP2.RING, SJ3.2
unnamed: R13.2, SJ3.1
unnamed: C15.2, R13.1, R16.2
unnamed: LED2.A, R2.1
unnamed: R14.2, U7.34
unnamed: C11.2, U7.44
unnamed: LED2.C, U1.5
unnamed: J1.VIN0, S2.2
unnamed: C14.1, R11.1
unnamed: C13.1, R10.1
unnamed: C12.1, R9.1
unnamed: R15.2, U7.33
unnamed: C5.A, F1.2, U4.3
unnamed: JP2.TIP, SJ2.2
unnamed: S2.6, SJ1.2
unnamed: LED3.A, R41.1
unnamed: R39.2, SJ2.1
unnamed: C16.2, R18.2, R39.1
unnamed: J2.VIN0, S4.2
unnamed: C21.2, Q2.3, R42.2, U8.18
unnamed: C22.2, Q2.1, R42.1, U8.17
unnamed: C23.2, U8.44
unnamed: C26.1, R46.1
unnamed: C25.1, R45.1
unnamed: C24.1, R44.1
unnamed: LED4.A, R40.1
unnamed: R50.1, R51.2, U12.1
unnamed: LED4.C, U6.5
unnamed: S4.6, SJ5.2
unnamed: R54.2, U8.34
unnamed: R55.2, U8.33
unnamed: C27.A, F2.2, U12.3
unnamed: JP4.SLEEVE, SJ6.2
unnamed: JP4.RING, SJ7.2
unnamed: R75.2, SJ7.1
unnamed: C31.2, R75.1, R76.2
unnamed: JP4.TIP, SJ8.2
unnamed: R78.2, SJ8.1
unnamed: C32.2, R77.2, R78.1
unnamed: LED5.A, R80.1
unnamed: J3.VIN0, S6.2
unnamed: C37.2, Q3.3, R81.2, U18.18
unnamed: C38.2, Q3.1, R81.1, U18.17
unnamed: C39.2, U18.44
unnamed: C42.1, R85.1
unnamed: C41.1, R84.1
unnamed: C40.1, R83.1
unnamed: LED6.A, R79.1
unnamed: R89.1, R90.2, U20.1
unnamed: LED6.C, U17.5
unnamed: S6.6, SJ9.2
unnamed: R93.2, U18.34
unnamed: R94.2, U18.33
unnamed: C43.A, F3.2, U20.3
unnamed: JP14.SLEEVE, SJ10.2
unnamed: JP14.RING, SJ11.2
unnamed: R114.2, SJ11.1
unnamed: C47.2, R114.1, R115.2
unnamed: JP14.TIP, SJ12.2
unnamed: R117.2, SJ12.1
unnamed: C48.2, R116.2, R117.1
unnamed: LED7.A, R119.1
unnamed: J4.VIN0, S8.2
unnamed: C53.2, Q4.3, R120.2, U26.18
unnamed: C54.2, Q4.1, R120.1, U26.17
unnamed: C55.2, U26.44
unnamed: C58.1, R124.1
unnamed: C57.1, R123.1
unnamed: C56.1, R122.1
unnamed: LED8.A, R118.1
unnamed: R128.1, R129.2, U28.1
unnamed: LED8.C, U25.5
unnamed: S8.6, SJ13.2
unnamed: R132.2, U26.34
unnamed: R133.2, U26.33
unnamed: C59.A, F4.2, U28.3
unnamed: JP20.SLEEVE, SJ14.2
unnamed: JP20.RING, SJ15.2
unnamed: R153.2, SJ15.1
unnamed: C63.2, R153.1, R154.2
unnamed: JP20.TIP, SJ16.2
unnamed: R156.2, SJ16.1
unnamed: C64.2, R155.2, R156.1
unnamed: LED9.A, R158.1
unnamed: J5.VIN0, S10.2
unnamed: C69.2, Q5.3, R159.2, U34.18
unnamed: C70.2, Q5.1, R159.1, U34.17
unnamed: C71.2, U34.44
unnamed: C74.1, R163.1
unnamed: C73.1, R162.1
unnamed: C72.1, R161.1
unnamed: LED10.A, R157.1
unnamed: R167.1, R168.2, U36.1
unnamed: LED10.C, U33.5
unnamed: S10.6, SJ17.2
unnamed: R171.2, U34.34
unnamed: R172.2, U34.33
unnamed: C75.A, F5.2, U36.3
unnamed: JP26.SLEEVE, SJ18.2
unnamed: JP26.RING, SJ19.2
unnamed: R192.2, SJ19.1
unnamed: C79.2, R192.1, R193.2
unnamed: JP26.TIP, SJ20.2
unnamed: R195.2, SJ20.1
unnamed: C80.2, R194.2, R195.1
unnamed: LED11.A, R197.1
unnamed: J6.VIN0, S12.2
unnamed: C85.2, Q6.3, R198.2, U42.18
unnamed: C86.2, Q6.1, R198.1, U42.17
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

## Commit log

2015-03-10 Adding hardware files, updating README
    [mp3-trigger-v23.brd, mp3-trigger-v23.sch]
2015-07-09 V24 preliminary rerouting finished
    New V24 preliminary rerouting finished after adding pulp and jumpers on
    audio lines.
    [mp3-trigger-v23.brd, mp3-trigger-v23.sch, mp3-trigger.brd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]
2015-07-13 Minor changes from Toni K review
    Acid trap elimination, angles, added notes about jumpers, minor
    rerouting.
    [mp3-trigger.brd, mp3-trigger.sch]
2015-07-13 Added OSHW Logo
    Added OSHW Logo
    [mp3-trigger.brd, mp3-trigger.sch]
2015-07-29 QC Checklist Crrections
    Minor error fixes
    [mp3-trigger.brd, mp3-trigger.sch]
2015-09-24 Ready for reds
    Added Input Voltages to silk, bumped up cream for solder jumpers,
    centered logos on back.
    [mp3-trigger.brd, mp3-trigger.sch]
2015-09-29 FTDI Silk update
    Changed to 5V FTDI
    [mp3-trigger.brd, mp3-trigger.sch]
2015-09-29 Added Jumper key to Bottom Silk
    Added solder jumper key to denote which solder jumper configurations
    mean which audio output.
    [mp3-trigger.brd, mp3-trigger.sch]
2015-10-01 V24 Reds Checklist Updates
    See github for issues fixed
    [mp3-trigger.brd, mp3-trigger.sch]
2015-10-07 created panel v24
    [Mp3_Trigger_Panel_v24.brd]
2015-11-04 Updated RED LED to correct version w/ correct ID
    [mp3-trigger.brd, mp3-trigger.sch]

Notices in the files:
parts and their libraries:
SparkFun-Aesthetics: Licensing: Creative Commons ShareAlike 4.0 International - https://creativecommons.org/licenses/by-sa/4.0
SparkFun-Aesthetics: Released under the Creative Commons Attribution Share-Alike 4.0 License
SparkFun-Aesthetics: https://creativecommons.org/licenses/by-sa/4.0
